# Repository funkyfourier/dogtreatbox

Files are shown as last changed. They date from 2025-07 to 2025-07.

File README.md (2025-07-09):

# Box for dog treats with magnetic lid

Practical box intended for carrying dog treats with options for open and closed belt clip. The lid has embedded magnets for ease of use. Should be easily printed without supports, but requires pause during print to insert the magnets.

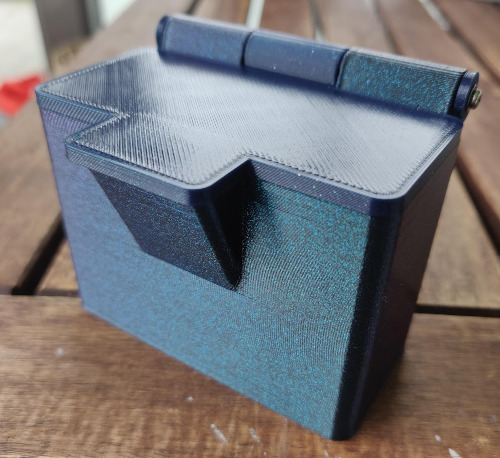
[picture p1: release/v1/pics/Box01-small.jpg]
Photo of dog treat box


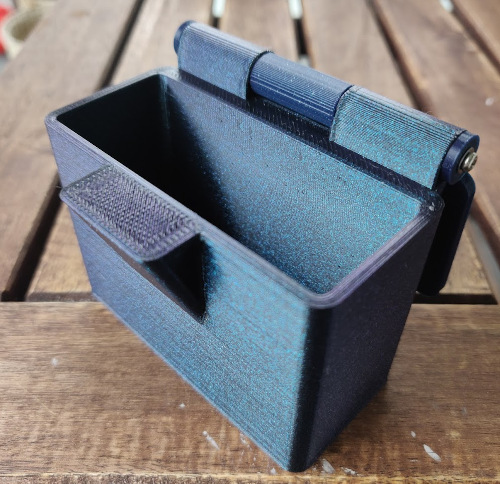
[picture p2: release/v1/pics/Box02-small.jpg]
Photo of dog treat box with lid opened


The box features two options for belt clips. One of them is a conventional open clip which slides on and off your belt easily:

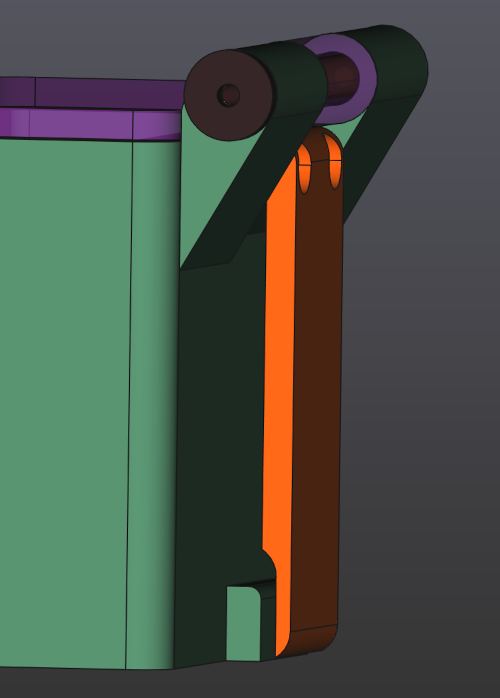
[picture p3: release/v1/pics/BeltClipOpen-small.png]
CAD screenshot of open belt clip


The other clip attaches permanently to your belt, and is more suitable when doing various dog sports or other hefty physical activity:

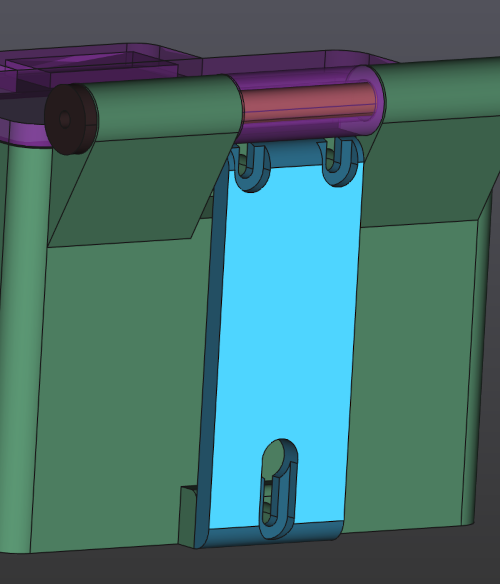
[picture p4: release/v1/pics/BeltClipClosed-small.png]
CAD screenshot of open belt clip


## How to print

None of the models require supports, so printing should be straight forward. Inserting the magnets will require some effort, though, see below.

The closed/permanent belt clip should be printed laying down, with 100% infill like this:

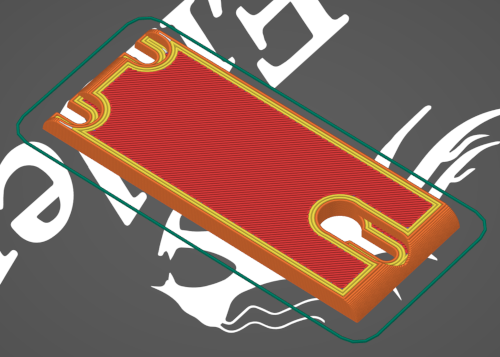
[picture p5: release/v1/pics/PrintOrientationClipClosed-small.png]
Print orientation closed belt clip


The open belt clip should be printed on its side with generous brims, something like this:

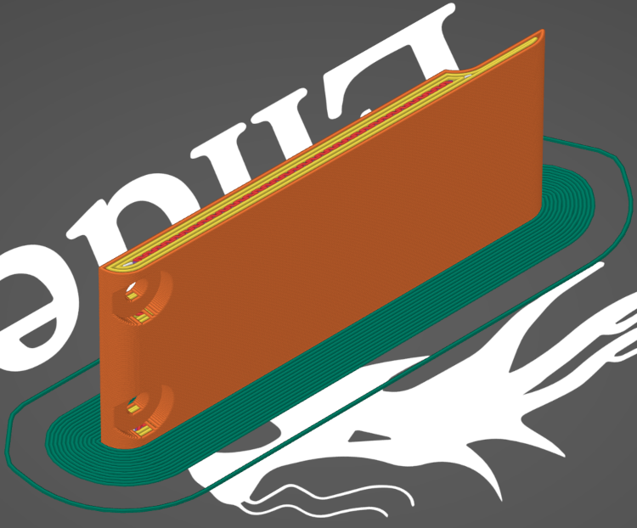
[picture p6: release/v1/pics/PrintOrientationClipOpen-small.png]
Print orientation closed belt clip


## Inserting magnets

The magnets are embedded into the print by pausing the print job. This is supported by most modern printers and slicers.

**IMPORTANT** Make sure to use some adhesive when inserting the magnets. In my case (using a more or less stock Ender 3), one of the magnets snapped on to the print head as it moved past the magnet. This might or might not be an issue on your printer.

 You can probably use some thin double sided tape, but **make sure the magnets do not protrude beyond the layer height**. If they do they will crash with the nozzle. Recommended method is a tiny bit of super glue and leave it for sufficient time to cure before resuming the print.

Pause the print before the first layer above the magnet compartment like this:

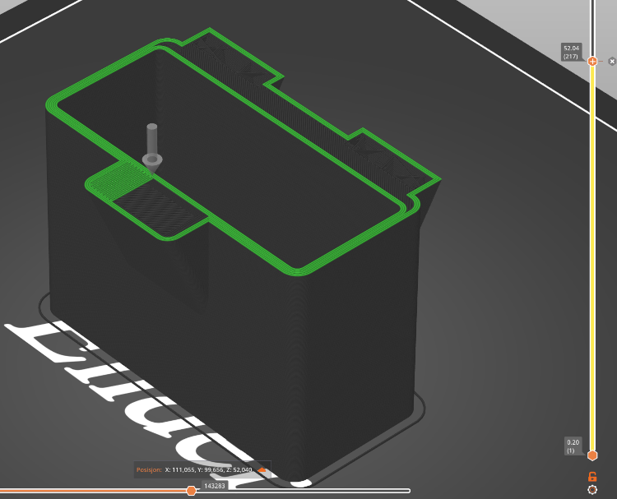
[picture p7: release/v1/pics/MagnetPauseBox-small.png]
Screenshot of slicer showing where to pause print


Similar for the lid:

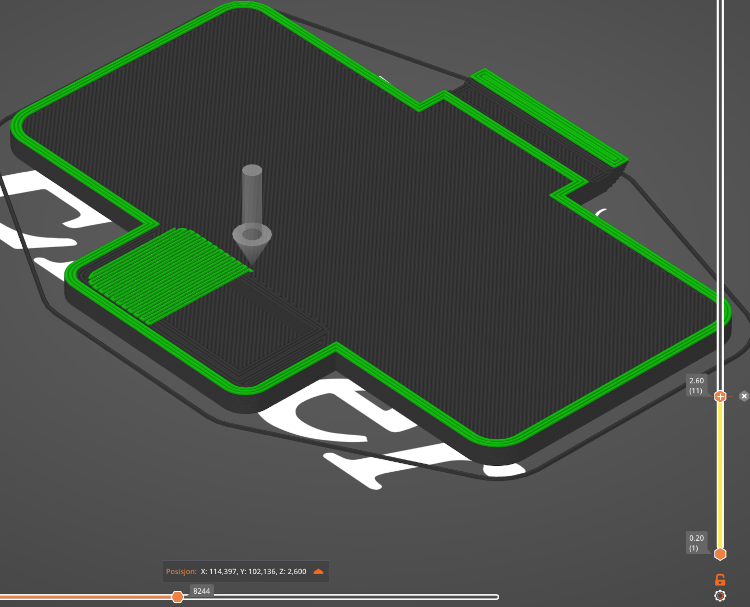
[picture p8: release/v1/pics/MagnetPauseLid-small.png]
Screenshot of slicer showing where to pause print


## Assembly

The lid is fastened on a rod which goes through the hinges on the back. To secure the rod two screws are mounted on each side of the rod. There is also a printed washer to make it look a bit nicer:

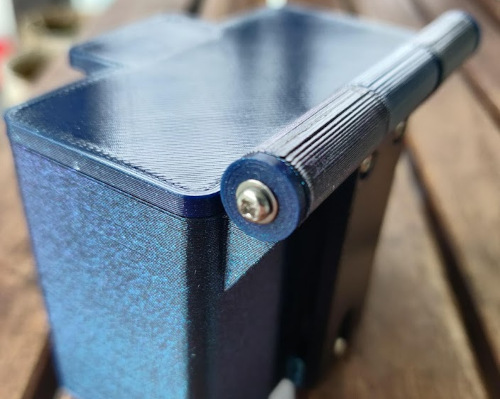
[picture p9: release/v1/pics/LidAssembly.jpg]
Lid assembly


The clips are fastened to threaded inserts inserts on the back side:

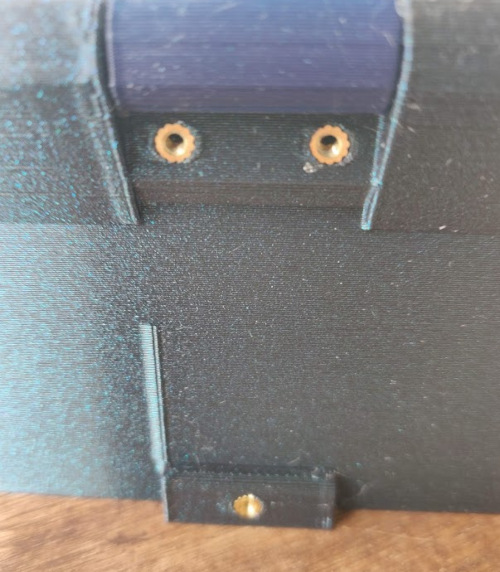
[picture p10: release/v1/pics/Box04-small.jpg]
Threaded inserts


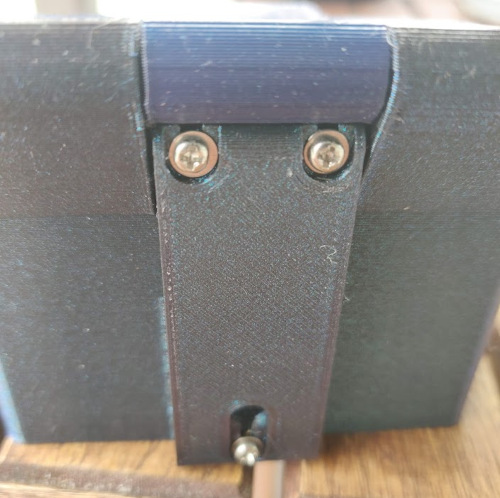
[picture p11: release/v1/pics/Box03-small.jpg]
Belt clip assembled


**IMPORTANT** Do not use screws longer than 8mm, or they will screw through the inner wall of the box:

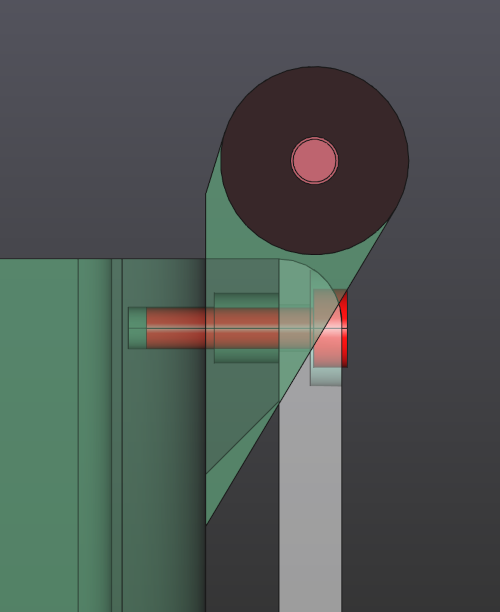
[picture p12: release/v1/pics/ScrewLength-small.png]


## Bill of materials

* 2 20x10X2mm magnets
* 5 M2 screws, **max 8mm length**
* 5 M2 washers, max 5mm diameter
* 3 M2 threaded inserts, 3mm length

## Remixing

The box is modelled in [FreeCAD](https://www.freecad.org/). If you open the spreadsheet you will see various parameters you can tweak to your liking. Changing the parameters may blow up the model, but adjusting them within reason should work. For learning FreeCAD [MangoJelly Solutions for FreeCAD](https://www.youtube.com/channel/UCUWhaOxsRk_5oPPq00_Y7Dw) is highly recommended.

## Disclaimer/warning on bottom

There is a disclaimer/warning on the bottom of the box advicing not to throw it in the dishwasher and using it for dry treats only. These warnings largely depends on the filament and 3d printer, but for conventional 3d printing with PLA they probably apply. There are .3mf files with and without the warning, so you can decide wether to keep them or not.

## License

This work is licensed under a [Creative Commons (4.0 International License) Attribution-NonCommercial](https://creativecommons.org/licenses/by-nc/4.0/)

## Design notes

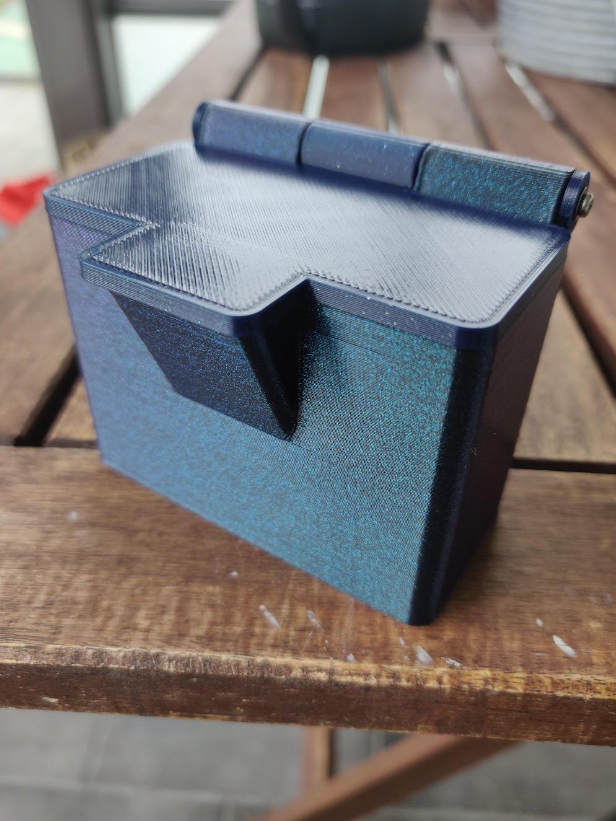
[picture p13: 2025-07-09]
release/v1/pics/Box01.jpg

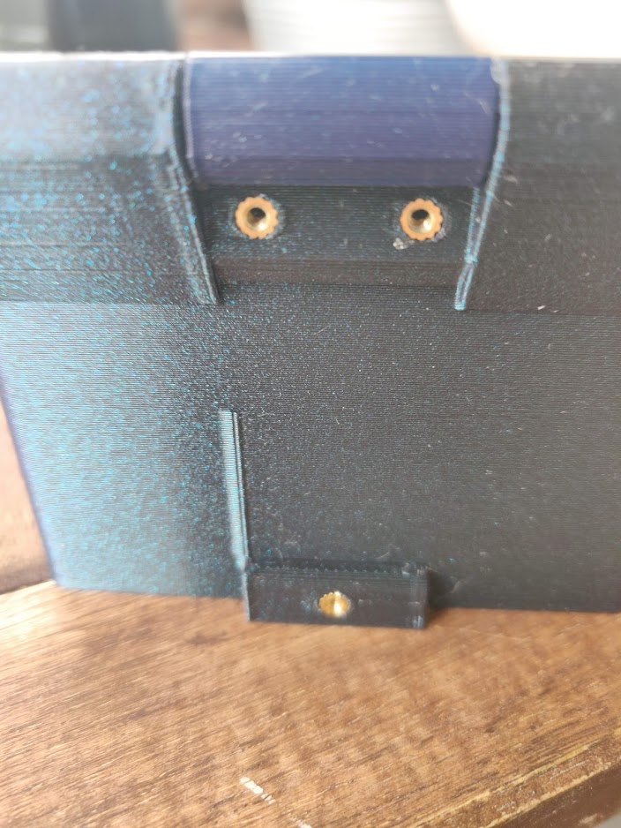
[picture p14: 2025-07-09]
release/v1/pics/Box04.jpg

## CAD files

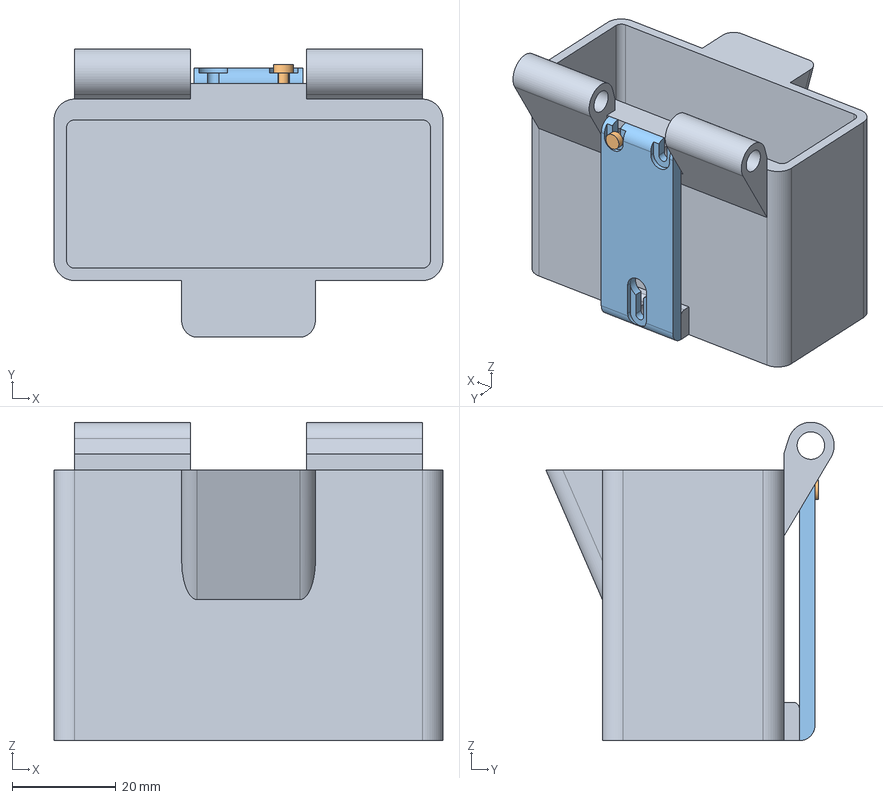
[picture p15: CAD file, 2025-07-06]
dogtreatbox.FCStd
75.0 x 55.6 x 61.4 mm
Screw
ClipNew

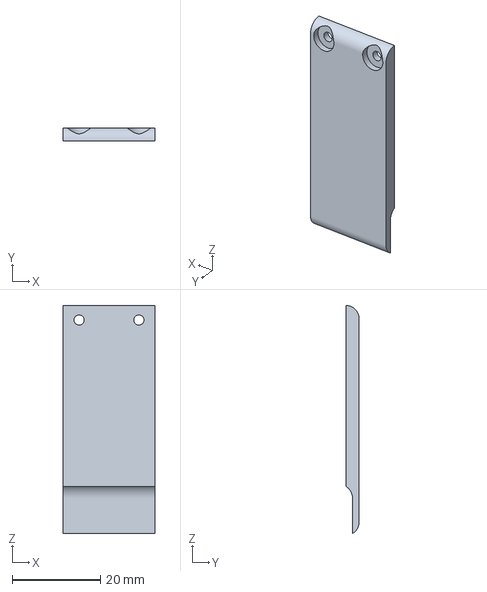
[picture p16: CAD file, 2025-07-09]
release/v1/printables/ClipOpen.3mf
21.0 x 3.00 x 51.8 mm

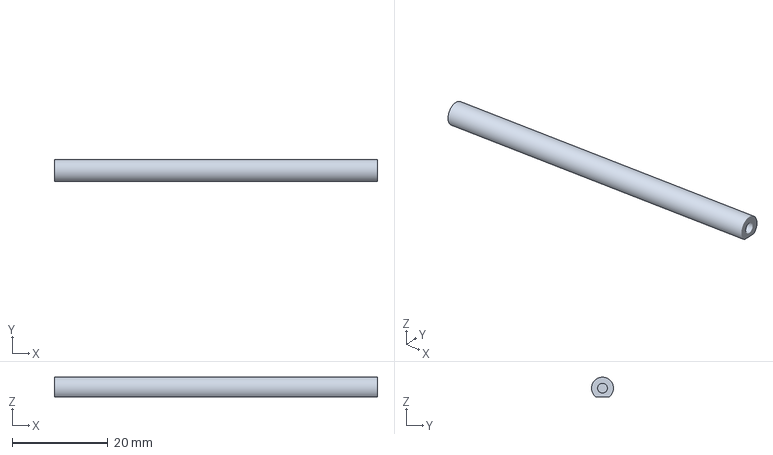
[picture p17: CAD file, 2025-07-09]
release/v1/printables/Pin.3mf
67.6 x 4.60 x 4.12 mm

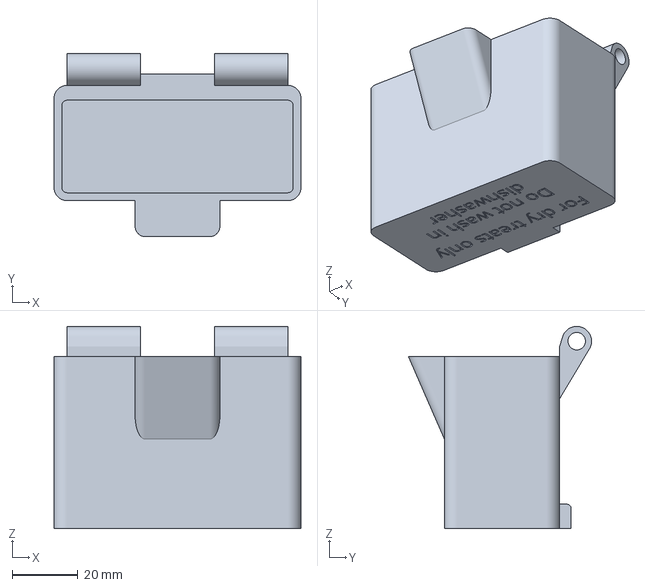
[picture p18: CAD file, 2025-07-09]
release/v1/printables/Box-Warning.3mf
75.0 x 55.6 x 61.4 mm

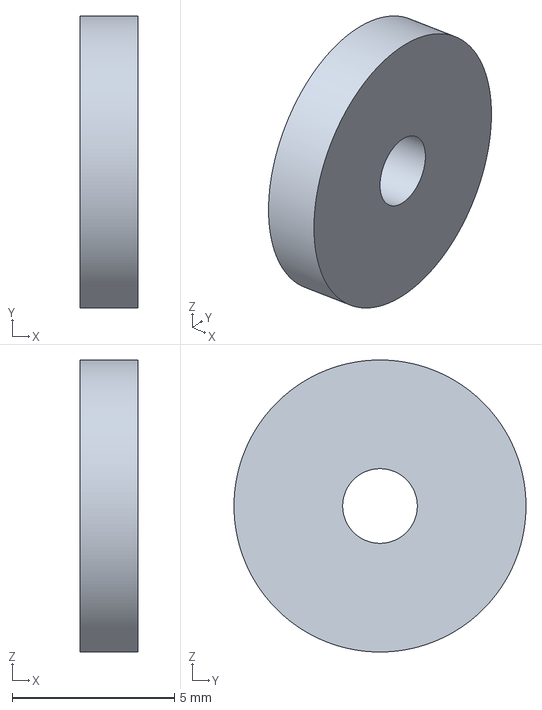
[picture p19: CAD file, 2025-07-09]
release/v1/printables/PinStopper.3mf
1.80 x 9.00 x 9.00 mm

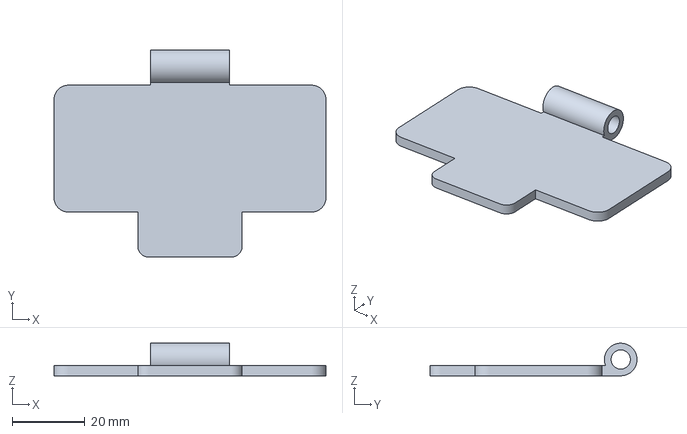
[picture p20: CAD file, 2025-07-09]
release/v1/printables/Lid.3mf
75.0 x 57.1 x 9.00 mm

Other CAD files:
release/v1/printables/Box-NoWarning.3mf
release/v1/printables/ClipClosed.3mf

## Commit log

2023-08-29 First print of box
    [dogtreatholder.FCStd]
2023-09-17 Adjusted dimensions
    [dogtreatholder.FCStd]
2024-12-14 Renamed file
    [dogtreatbox.FCStd, dogtreatholder.FCStd]
2024-12-14 Converted to FreeCAD 1.0
    [dogtreatbox.FCStd]
2024-12-14 New magnets in place
    [dogtreatbox.FCStd]
2024-12-14 Mounts for belt clip
    [dogtreatbox.FCStd]
2024-12-14 Belt clip done
    [dogtreatbox.FCStd]
2024-12-14 Constant width for belt clip
    [dogtreatbox.FCStd]
2024-12-14 Added disclaimer text on the bottom
    [dogtreatbox.FCStd]
2025-03-22 Adjusted magnet dimensions
    [dogtreatbox.FCStd]
2025-03-22 Adjusted magnet compartment ramp on lid
    [dogtreatbox.FCStd]
2025-03-22 Seperate lid thickness to accomodate magnet thickness
    [dogtreatbox.FCStd]
2025-03-22 Removed magnet compartment ramp
    [dogtreatbox.FCStd]
2025-03-22 Adjusted magnet dimensions ever so slightly
    [dogtreatbox.FCStd]
2025-03-22 Adjusted m2 screw hole diameter
    [dogtreatbox.FCStd]
2025-03-22 Added open belt clip
    [dogtreatbox.FCStd]
2025-03-22 Adjusted position of hinge pin and stopper
    [dogtreatbox.FCStd]
2025-03-22 Screw hole diameter for hinge pin
    [dogtreatbox.FCStd]
2025-03-22 Adjusted pin diameters
    [dogtreatbox.FCStd]
2025-03-22 Added lip to lid
    [dogtreatbox.FCStd]
2025-03-22 Renamed belt clip to clip open
    [dogtreatbox.FCStd]
2025-03-22 Increased clip width
    [dogtreatbox.FCStd]
2025-03-23 Increased pin tolerance
    [dogtreatbox.FCStd]
2025-03-23 Decreased pin tolerance a little bit
    [dogtreatbox.FCStd]
2025-04-27 Pin screw hole size from spreadsheet value
    [dogtreatbox.FCStd]
2025-04-29 Adjusted pin tolerance back to 0.7
    [dogtreatbox.FCStd]
2025-07-06 New clip mounts with self threading portion
    [dogtreatbox.FCStd]
2025-07-06 Made back wall thicker to better accomodate screw
    [dogtreatbox.FCStd]
2025-07-06 Begun implementing new clip
    [dogtreatbox.FCStd]
2025-07-06 Closed clip finished
    [dogtreatbox.FCStd]
2025-07-06 First iteration of open clip
    [dogtreatbox.FCStd]
2025-07-07 Test printed and adjusted some dimensions
2025-07-07 Made dimensions of top clip mount independant of hinges
2025-07-09 Increased screw hole diameter for pin stoppers
2025-07-09 Added pics and printables for v1 release
    [Box-NoWarning.3mf, Box-Warning.3mf, ClipClosed.3mf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]
2025-07-09 Smaller versions of pics
    [ClipOpen.3mf]
2025-07-09 Screenshots of belt clips
